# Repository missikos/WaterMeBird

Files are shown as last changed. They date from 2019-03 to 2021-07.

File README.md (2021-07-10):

# WaterMeBird

Water Me Bird - Packet

##Video Instructions
https://www.youtube.com/playlist?list=PLXV-vJmVgkyYVAK37a0ae-BBcncbxYWD5

#Advanced:

##PCB:
TBA

##Programming:
TBA



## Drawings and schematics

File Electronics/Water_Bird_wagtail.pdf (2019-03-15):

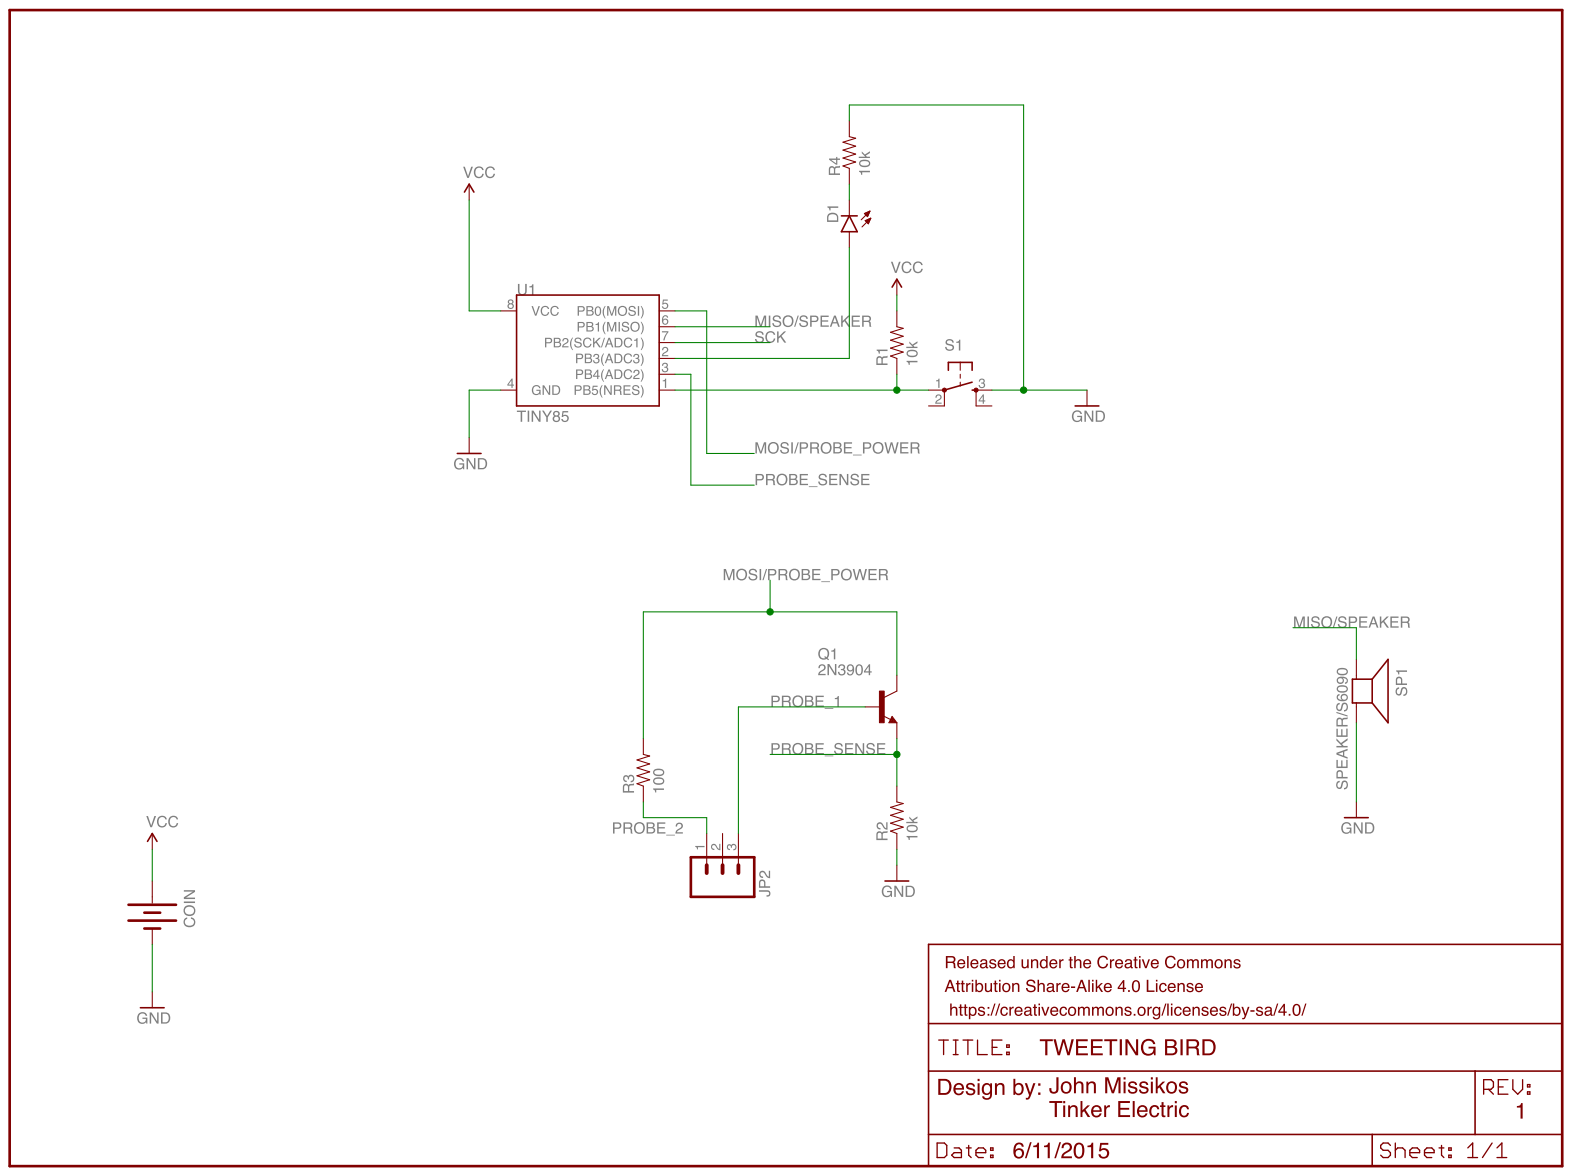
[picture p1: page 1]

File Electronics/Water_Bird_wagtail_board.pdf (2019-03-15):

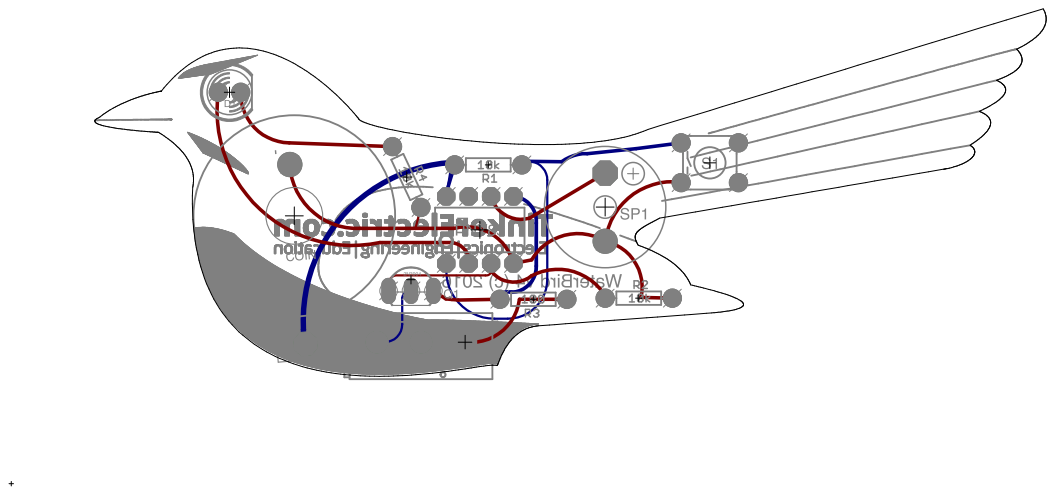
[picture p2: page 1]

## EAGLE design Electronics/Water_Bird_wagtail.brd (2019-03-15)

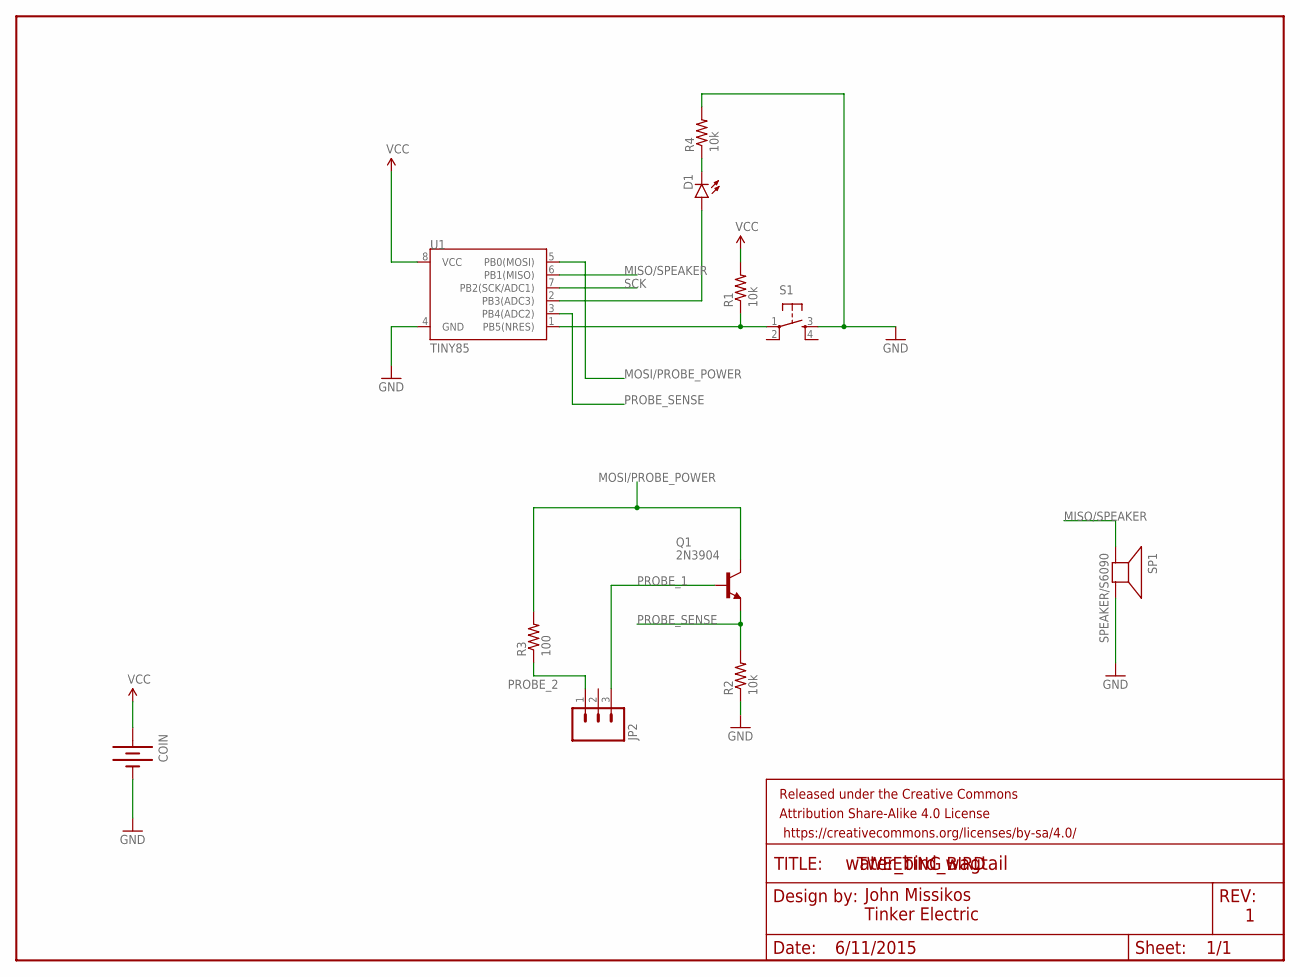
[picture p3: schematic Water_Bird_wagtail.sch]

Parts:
COIN: BATTERY_20MM20PTH; BATTCOM_20MM_PTH
D1: LED5MM
FRAME1: FRAME-LETTERNO_PACKAGE; DUMMY
JP2: M03-SCREW-5MM; SCREWTERMINAL-5MM-3
Q1: 2N3904; TO92-EBC-OVAL
R1, R2, R4: 10k; AXIAL-0.3
R3: 100; AXIAL-0.3
S1: TAC_SWITCHPTH; TACTILE-PTH
SP1: SPEAKER/S6090; S6090
U1: TINY85; DIP08

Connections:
GND: COIN.2 (-), R2.P$1 (1), R4.P$2 (2), S1.3, SP1.2 (-), U1.4 (GND)
MISO/SPEAKER: SP1.1 (+), U1.6 (PB1(MISO))
MOSI/PROBE_POWER: Q1.C, R3.P$2 (2), U1.5 (PB0(MOSI))
unnamed: D1.A, U1.2 (PB3(ADC3))
unnamed: D1.K (C), R4.P$1 (1)
PROBE_1: JP2.3, Q1.B
PROBE_2: JP2.1, R3.P$1 (1)
PROBE_SENSE: Q1.E, R2.P$2 (2), U1.3 (PB4(ADC2))
RESET: R1.P$1 (1), S1.1, U1.1 (PB5(NRES))
SCK: U1.7 (PB2(SCK/ADC1))
VCC: COIN.1 (+), R1.P$2 (2), U1.8 (VCC)

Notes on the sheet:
TWEETING BIRD
John Missikos Tinker Electric
6/11/2015

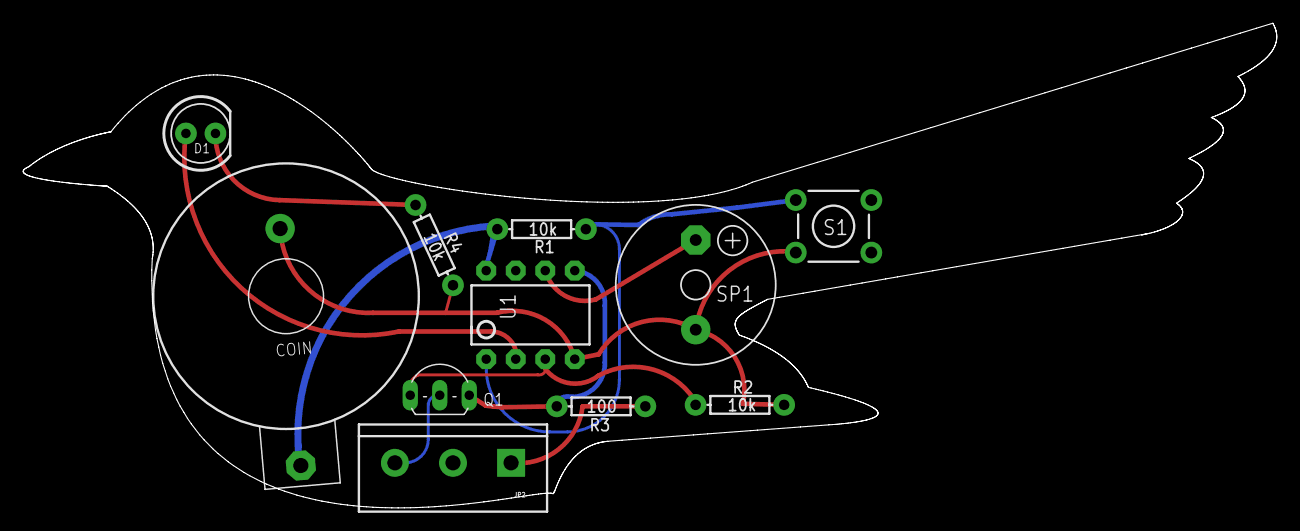
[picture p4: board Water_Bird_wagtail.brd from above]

Board: 2 copper layers, 107.9 x 41.7 mm, 12 parts (0 on the bottom side), 10 nets.

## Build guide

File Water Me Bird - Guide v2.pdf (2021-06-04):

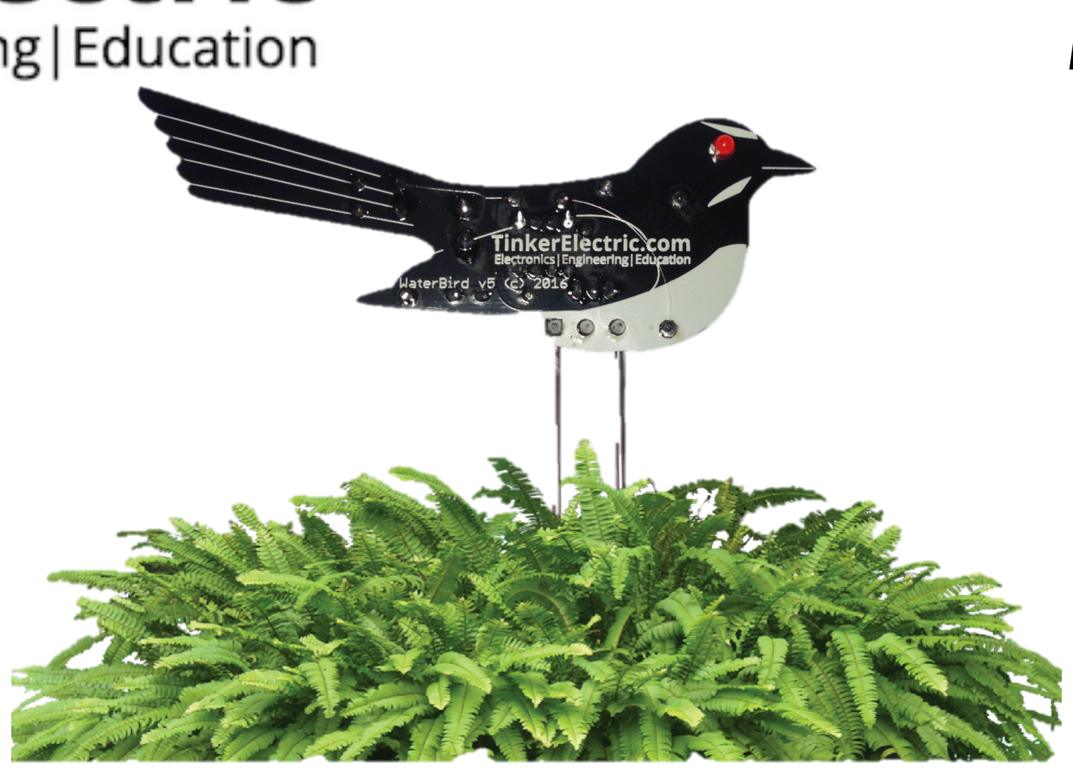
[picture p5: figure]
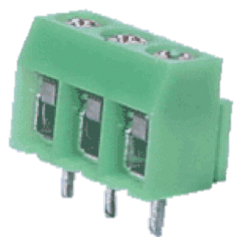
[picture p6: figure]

www.TinkerElectric.com

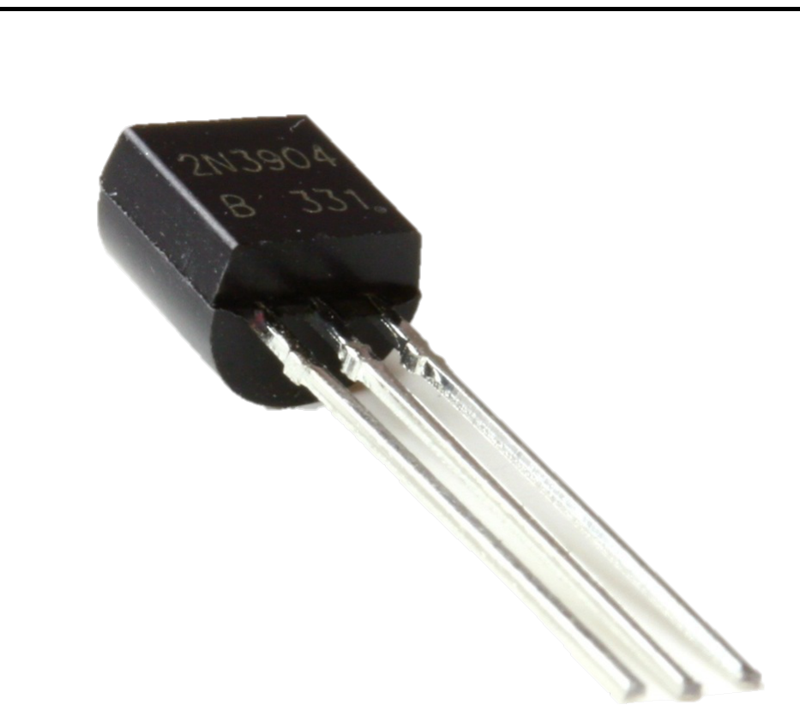
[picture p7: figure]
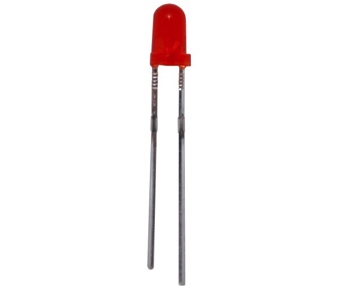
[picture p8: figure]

Electronics | Engineering | Education

# Water Me Bird

# kit instructions

Welcome to the Water Me Bird kit! This savvy bird knows when your plants need water and will tweet to let you know.

She does this by measuring the resistance of the soil, when it gets too low the microcontroller (brain) starts the chirp to let your plant is thirsty.

Remember not to water the electronics. =S
–John Missikos

## What’s in the kit:

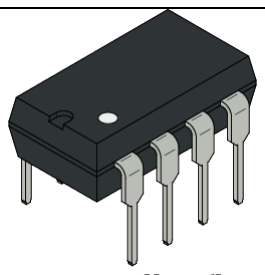
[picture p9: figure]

Microcontroller (brain) Find the dot | U1 Socket holder, find the notch | SP1 Buzzer, find the (+)
S2 Switch | R1, R2, R4 Resistor 10k Ω (Brown, Black, Black, Red, Brown) | R3 Resistor 100 Ω (Brown, Black, Black, Black, Brown)
Q1 Transistor – Find the curved back | JP2 Screw Terminal (holes face outward) | D1 LED – Find the short side

3V Battery
CR2032 Type

Bird PCB
Printed Circuit Board

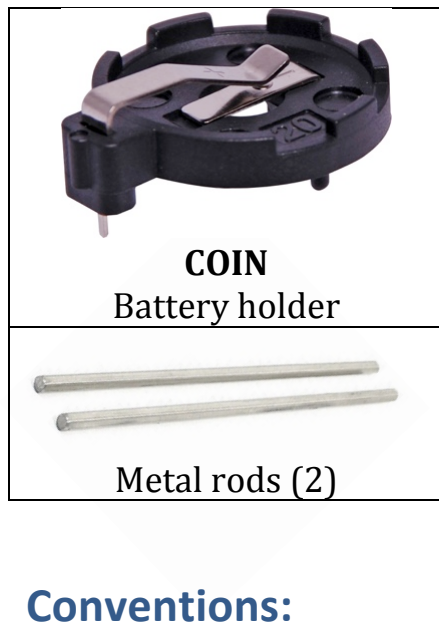
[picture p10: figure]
COIN Battery holder; Metal rods (2); Conventions:

Each part is given a part number like R1 for the resistors, Q1 for the transistor. This helps you find where it will be placed on the PCB (blue bird which is a circuit with wires in it!).

## Construction:

1. Solder Resistor R3: 100 Ω resistor (Brown, Black, Black, Black, Brown)
2. Solder Resistors R1,R2 and R4 10k Ω resistor (Brown, Black, Black, Red, Brown)
3. Solder Transistor Q1. Remember to align the flat side.
4. Solder U1 the socket holder. Align the notch to the front

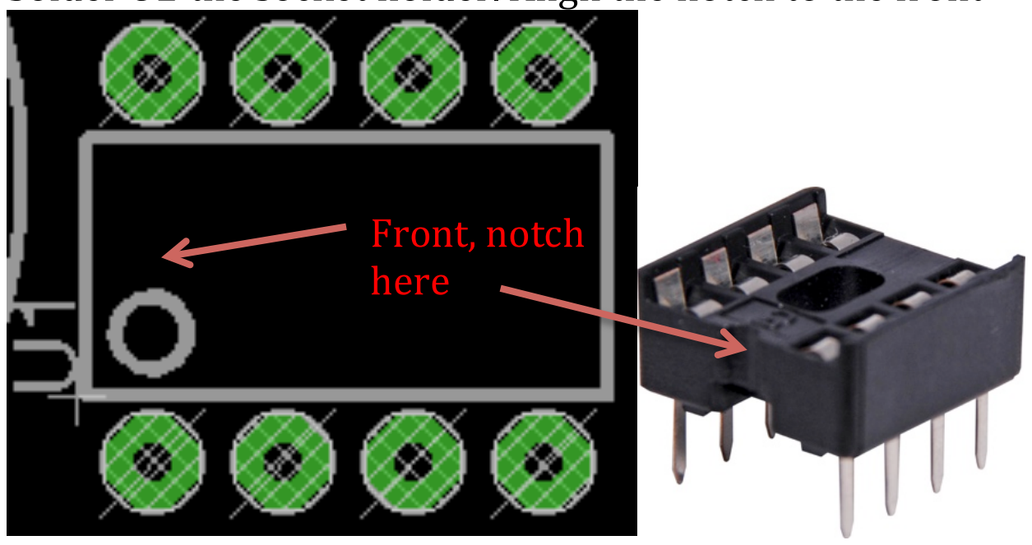
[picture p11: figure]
Front, notch here

5. Solder Switch S2. Note the legs come out on the left and right
6. Solder Speaker SP1. Align the (+) with that on the board
7. Solder COIN. The battery holder has a distinct circle to be aligned.
8. Solder red LED D1. Note the red plastic has a flat side that aligns with the marker. Flat side to the right.
9. Solder the screw terminal JP2. Note the open holes face down. They will hold the metal rods.

10. Unscrew the terminals JP2 to allow for the size of the rods. Screw the metal rods into JP2 on the left and right. Leave the middle one empty.
11. Note the microcontroller has a notch and dot at the front. Align this with the front of U1 on the board. When inserting it ensure the legs don’t bend out of the socket.
12. The coin battery is to have the (+) face upward. Insert the battery. She is alive. Congrats.

## Operation

1. Insert the bird’s legs into DRY soil, pack it around the legs.
2. Press the button to tell it what dry is. You have now told the bird to tweet when the soil is like this. It will now chatter away periodically.
3. Water your plant, the bird will now go to sleep
4. When the soil is dry again the bird will tweet periodically.

## Trouble shooting

- No sound or light – check battery (+) is face up. Ensure microcontroller has the notch facing left. Ensure LED has flat side on the right.
- No light, but tweets - Ensure LED has flat side on the right.
- No tweet but light – Ensure speaker has (+) at top
- Tweets once then nothing – The bird thinks it is wet. Place it in soil, then press the button to tell it’s dry. Chirping should begin. Then water plant and chirping will stop.
- Check transistor is correctly aligned for any other issue

## How it works

The microcontroller is a special chip allowing you to program what happens (outputs like speakers and lights) when it detects certain inputs (water detecting legs). In the case of the bird, the controller is told: when you see the resistance between its legs is high (i.e. nothing conducting) then do a tweeting pattern though the speaker and led (output). Repeat this until you see conduction (water helps). If you have seen water for a while, go to sleep more and more to save battery.

## Going Further

The code and circuit for the bird is available at: www.tinkerelectric.com/products/water-me-bird/
This allows you to see how it works and modify it. For more on electronics visit us at: www.TinkerElectric.com

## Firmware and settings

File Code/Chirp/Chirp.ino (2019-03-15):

//#define   F_CPU   1000000UL
#include <util/delay.h>
#include <avr/sleep.h> //Needed for sleep_mode
#include <avr/wdt.h> //Needed to enable/disable watch dog timer


//#include <SoftwareSerial.h>

//SoftwareSerial mySerial(2, 1); // RX, TX

//Pin definitions for regular Arduino Uno (used during development)
/*
const byte buzzer1 = 8;
const byte statLED = 13;
const byte waterSensor = A0;
const byte waterSensorPower = 7; //the digital pin for the moisture probe power (you power intermittent as to reduce corrosion)
*/
 
 
const byte buzzer1 = 1;//5;//1; //the digital pin for the piezo speaker
const byte statLED = 3;//6;//0; // for indications
const byte waterSensor = 2;//A4;//4; //the analog pin for the moisture probe (take reading only after turning on power pin)
const byte waterSensorPower = 0; //the digital pin for the moisture probe power (you power intermittent as to reduce corrosion)
//int watchdog_counter = 0;


 

//Pin definitions for ATtiny
/*const byte buzzer1 = 0;
const byte buzzer2 = 1;
const byte statLED = 4;
const byte waterSensor = A1;*/

//Variables

//This is the average analog value found during startup. Usually ~995
//When hit with water, the analog value will drop to ~400. A diff of 100 is good.
int minWetness = 0; 
//int maxDifference = 0; //A diff of more than 100 in the analog value will trigger the system.

  int timesWithoutAlarm = 0; //track number of times havent had an issue so can go deeper
  int timesBeforeDeepSleep = 5; //number of times to not have an issue before going deeper



//This runs each time the watch dog wakes us up from sleep
ISR(WDT_vect) {
  //Don't do anything. This is just here so that we wake up.
  //watchdog_counter++;
}


//Read sensor
int readSensorAvg(){
  int wetness = 0;
  
  //boot sensor power
  digitalWrite(waterSensorPower,HIGH);
  delay(50); //stabalise, may not be needed
  for(int x = 0 ; x < 8 ; x++)
    {
      wetness += analogRead(waterSensor);
  
      //During power up, blink the LED to let the world know we're alive
      if(digitalRead(statLED) == LOW)
        digitalWrite(statLED, HIGH);
      else
        digitalWrite(statLED, LOW);
  
      delay(50);
    }
    digitalWrite(waterSensorPower,LOW);
  wetness /= 8;
  wetness = map(wetness, 0, 1023, 0, 100); 
  return wetness;
}




long readVcc() {
  // Read 1.1V reference against AVcc
  // set the reference to Vcc and the measurement to the internal 1.1V reference
  //#if defined(__AVR_ATmega32U4__) || defined(__AVR_ATmega1280__) || defined(__AVR_ATmega2560__)
  //  ADMUX = _BV(REFS0) | _BV(MUX4) | _BV(MUX3) | _BV(MUX2) | _BV(MUX1);
  //#elif defined (__AVR_ATtiny24__) || defined(__AVR_ATtiny44__) || defined(__AVR_ATtiny84__)
  //  ADMUX = _BV(MUX5) | _BV(MUX0);
  //#elif defined (__AVR_ATtiny25__) || defined(__AVR_ATtiny45__) || defined(__AVR_ATtiny85__)
    ADMUX = _BV(MUX3) | _BV(MUX2);
  //#else
  //  ADMUX = _BV(REFS0) | _BV(MUX3) | _BV(MUX2) | _BV(MUX1);
  //#endif  

  delay(2); // Wait for Vref to settle
  ADCSRA |= _BV(ADSC); // Start conversion
  while (bit_is_set(ADCSRA,ADSC)); // measuring

  uint8_t low  = ADCL; // must read ADCL first - it then locks ADCH  
  uint8_t high = ADCH; // unlocks both

  long result = (high<<8) | low;

  result = 1125300L / result; // Calculate Vcc (in mV); 1125300 = 1.1*1023*1000
  return result; // Vcc in millivolts
}







void setup()
{
  
  //Setup the processor speed
  //This doesn't work now, set via bootloader
  /*
  cli();
  CLKPR = (1<<CLKPCE);
  CLKPR = (0<<CLKPS0);
  CLKPR = (0<<CLKPS1);
  CLKPR = (1<<CLKPS2);
  CLKPR = (0<<CLKPS3);
  sei();
  */
  
  //Configure IO
  pinMode(buzzer1, OUTPUT);
  pinMode(statLED, OUTPUT);
  pinMode(waterSensorPower, OUTPUT);

  //pinMode(waterSensor, INPUT_PULLUP);
  pinMode(2, INPUT); //When setting the pin mode we have to use 2 instead of A1
  digitalWrite(2, HIGH); //Hack for getting around INPUT_PULLUP

  //mySerial.begin(9600);
  //mySerial.println("Wet Sensor");

  //Take a series of readings from the water sensor and average them
  minWetness = readSensorAvg(); //10 is buffer

  //mySerial.print("minWetness: ");
  //mySerial.println(minWetness);

  //During power up, beep the buzzer to verify function
  alarmSound();
  //delay(100);
  //alarmSound();

  digitalWrite(buzzer1, LOW);
  digitalWrite(statLED, LOW);
  

  //Power down various bits of hardware to lower power usage  
  set_sleep_mode(SLEEP_MODE_PWR_DOWN); //Power down everything, wake up from WDT
  sleep_enable();

}

void loop() 
{


  
  //Check for water
  ADCSRA |= (1<<ADEN); //Enable ADC

  
  
  int wetnessRead = readSensorAvg();

  
  //mySerial.print("minWetness: ");
  //mySerial.print(minWetness);
  //mySerial.print("Now: ");
  //mySerial.println(wetnessRead);
  

  
  
  if(wetnessRead <  minWetness+15) //Are we too Dry? 5 buffer as may not get as dry
  
  {
    wdt_disable(); //Turn off the WDT!!
    
    long startTime = millis(); //Record the current time
    long timeSinceBlink = millis(); //Record the current time for blinking
    timesWithoutAlarm=0; //alarm was triggered, track it
    digitalWrite(statLED, HIGH); //Start out with the LED on

    //Loop until we don't detect DRYNESS AND 2 seconds of CHIRP have completed
    while((millis() - startTime) < 2000)
    {
      alarmSound(); //Make noise!!

      if(millis() - timeSinceBlink > 100) //Toggle the LED every 100ms
      {
        timeSinceBlink = millis();

        if(digitalRead(statLED) == LOW) 
          digitalWrite(statLED, HIGH);
        else
          digitalWrite(statLED, LOW);
      }
      
      //sleep here for shorter time
      //use delay for now TODO:REPLACE!
      //delay(5000);
      
      

      
      

      //waterDifference = abs(analogRead(waterSensor) - minWetness); //Take a new reading
      //wetnessRead = analogRead(waterSensor);
      
      //mySerial.print("minWetness: ");
      //mySerial.print(minWetness);
      //mySerial.print("Now: ");
      //mySerial.println(wetnessRead);
    } //Loop until we don't detect water AND 2 seconds of alarm have completed

    digitalWrite(buzzer1, LOW);
    digitalWrite(statLED, LOW); //No more alarm. Turn off LED
  } else {
    timesWithoutAlarm++; //didn't detect dryness,
  
  }
  
 
 
     //BATTERY WARNING: Chirp about battery warning here
     //Push out after thourough testing, would cause annoyance if wrong
      if (readVcc() < 2100){ //check voltage, Attiny stops at 1800mV, alarm less than 2100mV //set to 2800 for AtTiny85-20PU, set to 2100mV for AtTiny85V-10PU
        tweet(random(2,6),2);
      }
  
  //go to sleep for a bit
  
 //if this is the first bit, only go to sleep a little


//if havent alarmed for last 6 times go deep 
  
  if (timesWithoutAlarm < timesBeforeDeepSleep){
    //lite sleep
      ADCSRA &= ~(1<<ADEN); //Disable ADC, saves ~230uA
      setup_watchdog(9); //Setup watchdog to go off after 1sec
      sleep_mode(); //Go to sleep! Wake up 1sec later and check water
  
  }else{

    
    
    //deep sleep
    for (int i=0; i <= 6; i++){ //i is number of 9 second groups
        ADCSRA &= ~(1<<ADEN); //Disable ADC, saves ~230uA
        setup_watchdog(9); //Setup watchdog to go off after 1sec
        sleep_mode(); //Go to sleep! Wake up 1sec later and check water
    }
  }
  
  


  
  

      

      
      
      
      
  

}

//This is just a unique (annoying) sound we came up with, there is no magic to it
//Comes from the Simon Says game/kit actually: https://www.sparkfun.com/products/10547
//250us to 79us
void alarmSound(void)
{

  
  
   highChirp(random(5,9),random(3,8));
   delay(random(50,120));
   lowChirp(random(20,50)*4,random(2,5));
   delay(random(100));
   //tweet(random(2,6),2);
  lowChirp(random(20,50)*4,2);
  
  
}



void highChirp(int intensity, int chirpsNumber){
  int i;
  int x;
  
  for(int veces=0; veces<=chirpsNumber; veces++){
    for (i=100; i>0; i--){
     for  (x=0; x<intensity;  x++){
       digitalWrite (buzzer1,HIGH);
       delayMicroseconds (i);
       digitalWrite (buzzer1,LOW);
       delayMicroseconds (i);
     }
    }
  }
}

void lowChirp(int intensity, int chirpsNumber){
int i;
int x;

for(int veces=0; veces<=chirpsNumber; veces++){

for (i=0; i<200; i++)
{
   digitalWrite (buzzer1,HIGH);
   delayMicroseconds(i);
   digitalWrite(buzzer1,LOW);
   delayMicroseconds(i);
  }
   
  for (i=90; i>80; i--)
  {
   for  ( x=0; x<5;  x++)
   {
   digitalWrite (buzzer1,HIGH);
   delayMicroseconds (i);
   digitalWrite (buzzer1,LOW);
   delayMicroseconds (i);
   }
  }
}
}

void tweet(int intensity, int chirpsNumber){
  
  int i;
  int x;
  
  //normal chirpsNumber 3, normal intensity 5
  
  for(int veces=0; veces<chirpsNumber; veces++){
      
    for (int i=80; i>0; i--){
     for  (int x=0; x<intensity;  x++){
       digitalWrite (buzzer1,HIGH);
       delayMicroseconds (i);
       digitalWrite (buzzer1,LOW);
       delayMicroseconds (i);
     }
    }
  }
}






//Sets the watchdog timer to wake us up, but not reset
//0=16ms, 1=32ms, 2=64ms, 3=128ms, 4=250ms, 5=500ms
//6=1sec, 7=2sec, 8=4sec, 9=8sec
//From: http://interface.khm.de/index.php/lab/experiments/sleep_watchdog_battery/
void setup_watchdog(int timerPrescaler) {

  if (timerPrescaler > 9 ) timerPrescaler = 9; //Limit incoming amount to legal settings

  byte bb = timerPrescaler & 7; 
  if (timerPrescaler > 7) bb |= (1<<5); //Set the special 5th bit if necessary

  //This order of commands is important and cannot be combined
  MCUSR &= ~(1<<WDRF); //Clear the watch dog reset
  WDTCR |= (1<<WDCE) | (1<<WDE); //Set WD_change enable, set WD enable
  WDTCR = bb; //Set new watchdog timeout value
  WDTCR |= _BV(WDIE); //Set the interrupt enable, this will keep unit from resetting after each int
}

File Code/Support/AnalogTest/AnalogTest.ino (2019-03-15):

/*
  Analog Input
 Demonstrates analog input by reading an analog sensor on analog pin 0 and
 turning on and off a light emitting diode(LED)  connected to digital pin 13. 
 The amount of time the LED will be on and off depends on
 the value obtained by analogRead(). 
 
 The circuit:
 * Potentiometer attached to analog input 0
 * center pin of the potentiometer to the analog pin
 * one side pin (either one) to ground
 * the other side pin to +5V
 * LED anode (long leg) attached to digital output 13
 * LED cathode (short leg) attached to ground
 
 * Note: because most Arduinos have a built-in LED attached 
 to pin 13 on the board, the LED is optional.
 
 
 Created by David Cuartielles
 modified 30 Aug 2011
 By Tom Igoe
 
 This example code is in the public domain.
 
 http://arduino.cc/en/Tutorial/AnalogInput
 
 */

int sensorPin = A1;    // select the input pin for the potentiometer
int ledPin = 13;      // select the pin for the LED
int sensorValue = 0;  // variable to store the value coming from the sensor

void setup() {
  // declare the ledPin as an OUTPUT:
  pinMode(ledPin, OUTPUT);  
  pinMode(sensorPin, INPUT);  
  pinMode(A0, OUTPUT); 
 digitalWrite(A0, HIGH); 
Serial.begin(9600); 
}

void loop() {
  // read the value from the sensor:
  sensorValue = analogRead(sensorPin);  
Serial.println(sensorValue);   
  // turn the ledPin on
  //digitalWrite(ledPin, HIGH);  
  // stop the program for <sensorValue> milliseconds:
  delay(1000);          
  // turn the ledPin off:        
  //digitalWrite(ledPin, LOW);   
  // stop the program for for <sensorValue> milliseconds:
  //delay(sensorValue);                  
}

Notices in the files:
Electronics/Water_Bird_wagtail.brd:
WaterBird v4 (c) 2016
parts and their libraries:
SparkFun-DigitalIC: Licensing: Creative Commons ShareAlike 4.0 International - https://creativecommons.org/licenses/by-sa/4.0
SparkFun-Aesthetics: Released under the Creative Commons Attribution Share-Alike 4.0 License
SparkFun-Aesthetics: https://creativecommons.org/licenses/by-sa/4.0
